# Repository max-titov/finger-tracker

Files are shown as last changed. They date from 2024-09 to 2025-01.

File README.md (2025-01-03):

# Finger Tracker Glove

Hardware that attaches to the back of your hand and fingertips that tracks 16 degrees of freedom. 

<p float="left">
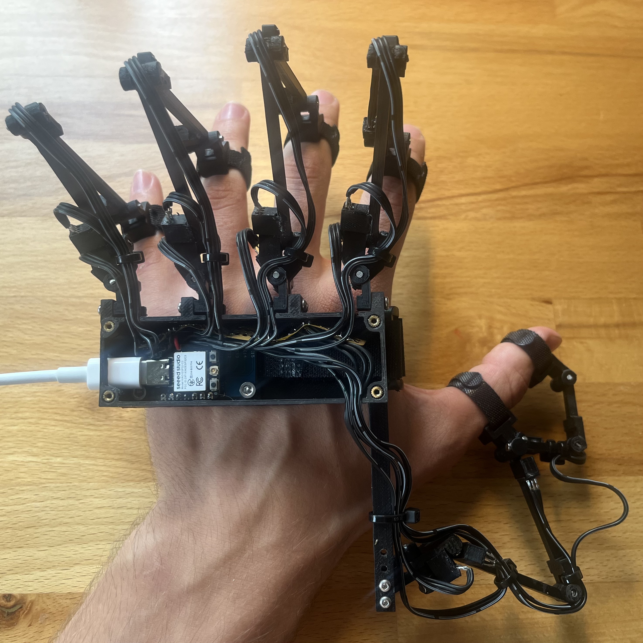
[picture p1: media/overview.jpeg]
  
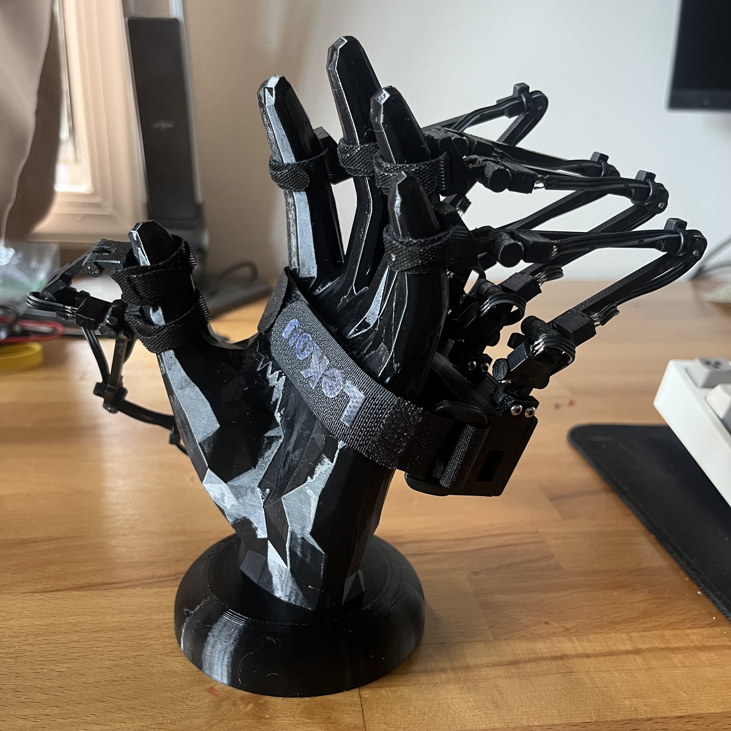
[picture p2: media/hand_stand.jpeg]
   
</p>

https://github.com/user-attachments/assets/3ccb0007-c99d-40c1-8628-71b2f0f8c4fa

## Description

The glove uses rotating neodymium magnets and hall effect sensors at each joint to measure rotation. The thumb has 4 sensors and the fingers have 3 each. Each sensor is wired up to a multiplexer and powered with a common GND/VCC strip. I used a XIAO ESP32C3 as the microcontroller for its small form factor. This project builds upon Nepyope's glove shown here: [Youtube](https://www.youtube.com/watch?v=iPtgvh6fNdQ).

## Getting Started

### 3D Printing

All the files are in the CAD folder. For Nepyope's parts I have just the STL with all of the pieces (and I dont use all of them). For my parts I have all of them as STLs and most of them have SLDPT and STEP versions.

Nepyope's Parts:
* 16x sensor boxes and lids
* Connecting rods (12 total, I used 11 of them as I changed one)
* 4x Finger second piece
* Thumb second piece

You can print the STL with all the parts and just use the ones listed above

My Parts:
* Enclosure
* Enclosure top
* Thumb bracket
* 4x finger endpiece
* Thumb endpiece
* Thumb middle piece
* Thumb first piece
* Thumb short rod (flipped from nepyope’s design)
* 4x Finger first joint

### Mechanical Hardware

* Finger straps [Amazon](https://www.amazon.com/dp/B0CJ52WJZY?ref=ppx_yo2ov_dt_b_fed_asin_title&th=1)
* Hand strap [Amazon](https://www.amazon.com/dp/B07CWV5JCT?ref=ppx_yo2ov_dt_b_fed_asin_title)
* 2mm steel pins
* M2 bolts and inserts
* M3 bolts and inserts
* 3mm by 3mm circular neodymium magnets [Amazon](https://www.amazon.com/dp/B0CCXYF5TR?ref=ppx_yo2ov_dt_b_fed_asin_title)

### Electrical Hardware

* Xiao ESP32C3
* 16 channel multiplexer [Amazon](https://www.amazon.com/dp/B01DLHKLNE?psc=1&ref=ppx_yo2ov_dt_b_product_details)
* 2.54mm pins
* 28 gauge 3 wire
* 28 gauge 1 wire
* 16x hall effect sensor [Amazon](https://www.amazon.com/dp/B09XQPCYNX?ref=ppx_yo2ov_dt_b_fed_asin_title)
* Flexible pcb [Adafruit](https://www.adafruit.com/product/1518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)

### Tools

* Soldering tools (iron, solder, flux, etc)
* Cutters, wire stripers, etc
* Superglue
* 1.5mm and 2.5mm allen keys

### Firmware

The firmware was made using PlatformIO in the Arduino framework. You can comment and uncomment the print functions to print raw values, adjusted angle values, or all the values in a single string. The raw value and adjusted angle values print in a way where Teleplot (serial plotter VSCode extension) can read and plot them. A teleplot layout is in the teleplot folder.

## License

This project is licensed under the MIT License - see the LICENSE file for details

## Acknowledgments

* [Nepyope Youtube](https://www.youtube.com/watch?v=iPtgvh6fNdQ)
* [Nepyope Github](https://github.com/nepyope/Project-Homunculus/tree/main)

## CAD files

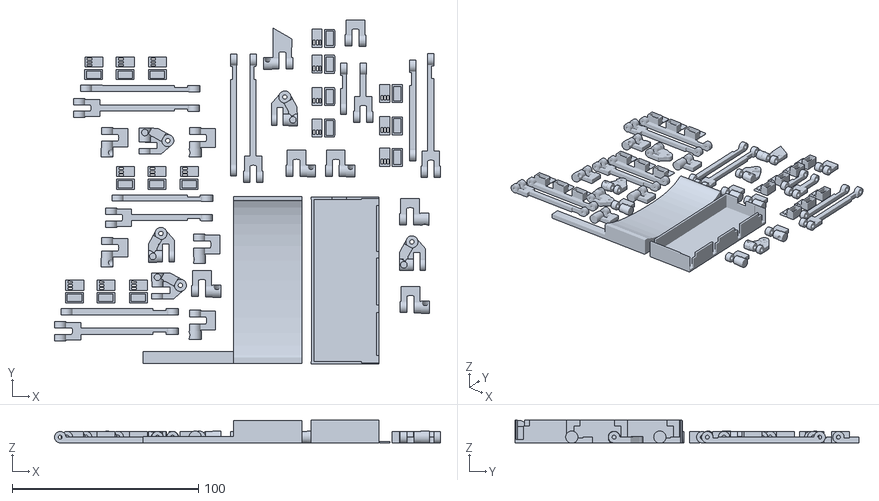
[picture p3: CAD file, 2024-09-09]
cad/homunculus_glove_nepyope.stl
207.2 x 184.7 x 12.3

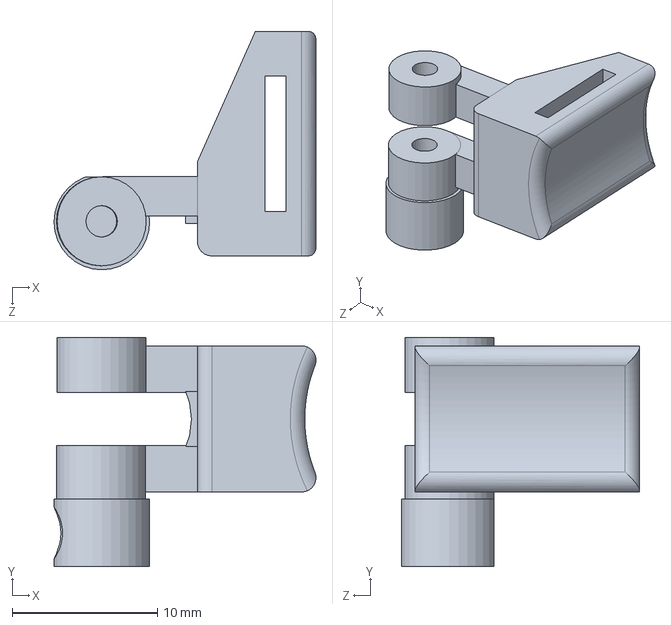
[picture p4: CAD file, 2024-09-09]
cad/SLDPRT/finger endpiece.SLDPRT
18.1 x 15.8 x 16.4 mm

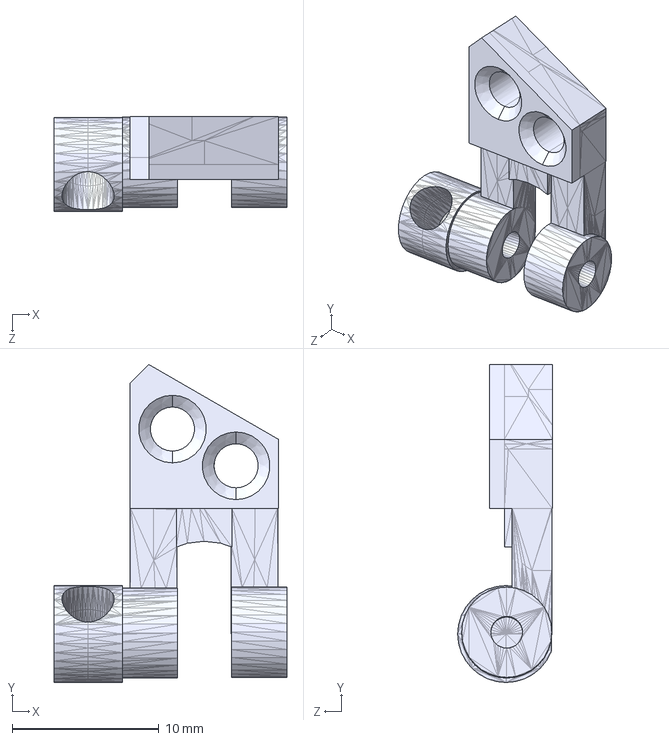
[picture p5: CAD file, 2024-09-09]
cad/STEP/thumb first piece v2.STEP
15.8 x 21.6 x 6.45 mm

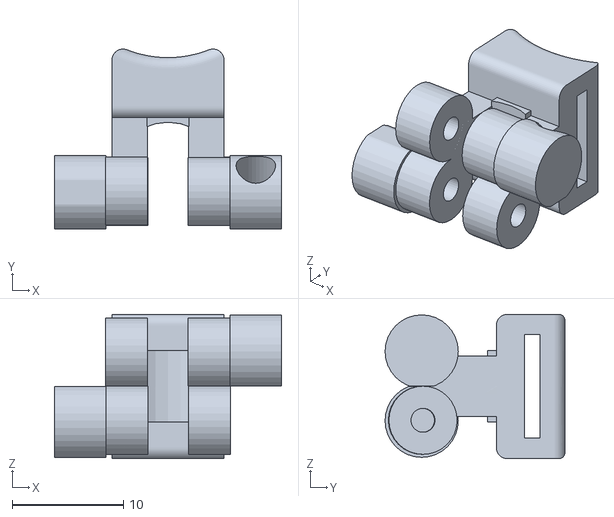
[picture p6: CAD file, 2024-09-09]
cad/STL/thumb middle v4.STL
20.4 x 16.2 x 13.0

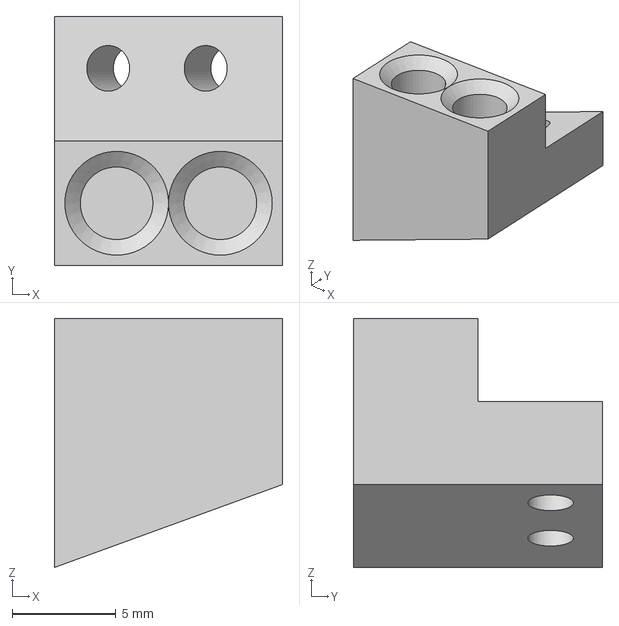
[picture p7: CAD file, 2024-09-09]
cad/STEP/thumb bracket v1.step
11.0 x 12.0 x 12.0 mm

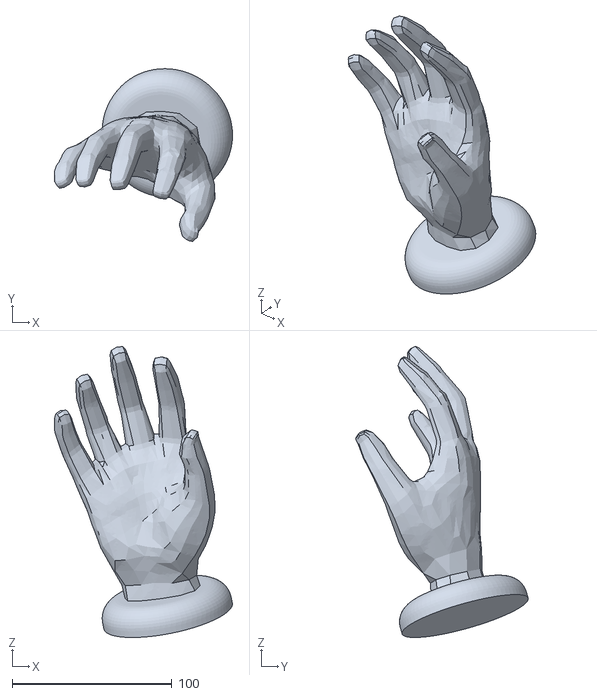
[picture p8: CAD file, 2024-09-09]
cad/STL/hand stand v1.stl
111.3 x 107.9 x 181.9

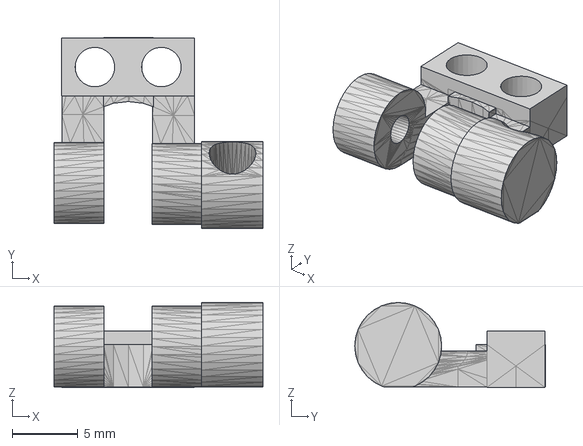
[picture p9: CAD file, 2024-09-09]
cad/STEP/first joint v2.step
15.8 x 14.5 x 6.45 mm

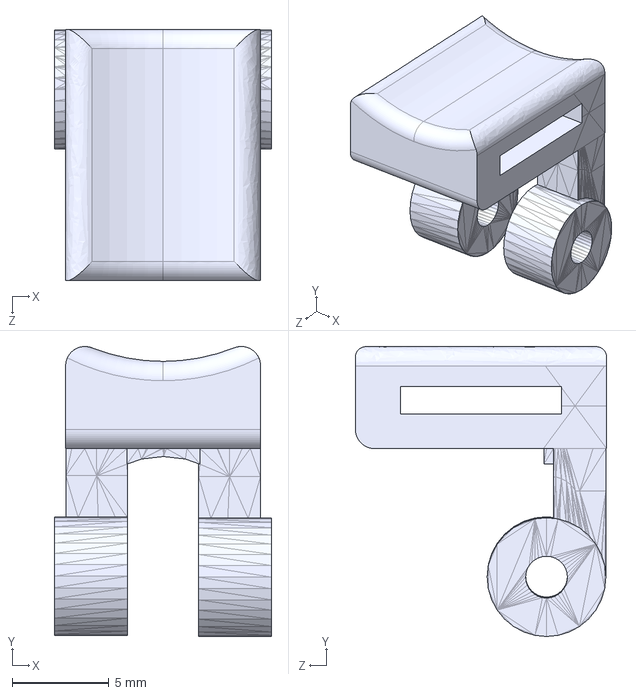
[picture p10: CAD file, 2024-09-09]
cad/STEP/thumb end v2.STEP
11.2 x 15.0 x 13.0 mm

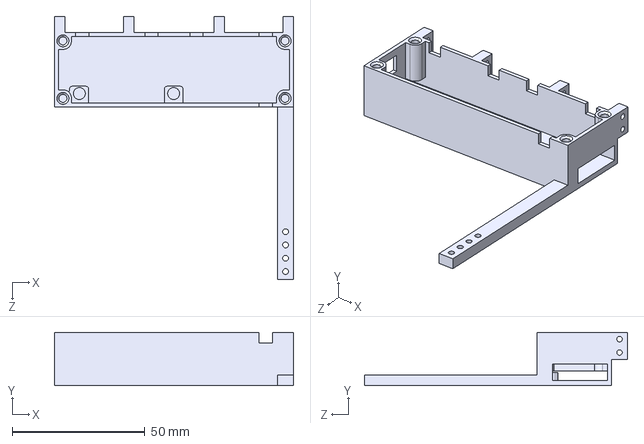
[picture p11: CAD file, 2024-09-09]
cad/STEP/enclosure v4.STEP
90.0 x 20.0 x 99.0 mm

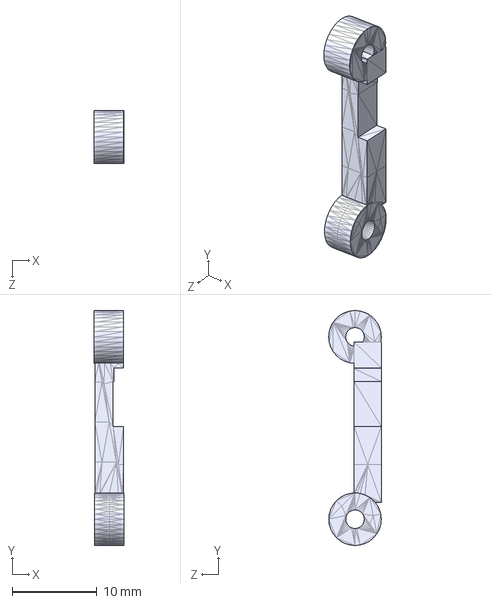
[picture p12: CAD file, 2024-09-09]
cad/STEP/thumb short rod v3.STEP
3.55 x 27.8 x 6.24 mm

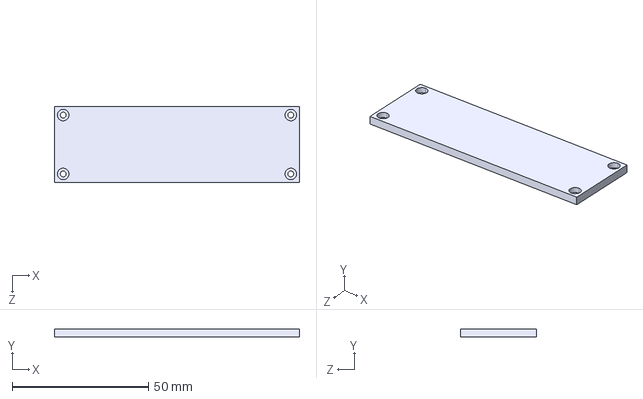
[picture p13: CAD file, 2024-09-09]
cad/STEP/enclosure top v2.STEP
90.0 x 3.00 x 28.0 mm

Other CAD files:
cad/SLDPRT/enclosure top v2.SLDPRT
cad/SLDPRT/enclosure v4.SLDPRT
cad/SLDPRT/thumb end v2.SLDPRT
cad/SLDPRT/thumb first piece v2.SLDPRT
cad/SLDPRT/thumb short rod v3.SLDPRT
cad/STL/enclosure top v2.STL
cad/STL/enclosure v4.STL
cad/STL/finger endpiece.STL
cad/STL/first joint v2.stl
cad/STL/thumb bracket v1.stl
cad/STL/thumb end v2.STL
cad/STL/thumb first piece v2.STL
cad/STL/thumb short rod v3.STL

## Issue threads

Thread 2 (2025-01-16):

Hall Effect sensors

sisyphean-task, 2025-01-16:
Hi,

I've been trying to build this project for use with the Dexhand as well, but I'm a bit confused in a few areas, particularly surrounding the hall effect sensors.
First, how are they oriented in the boxes? I have a rough sketch below with my potential assumptions from your and nepyope's implementations, but it is hard to tell where they are when obfuscated.
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

Also, when turning the output from the sensors into an angle, I noticed a polynomial approximation was used to map the presumably nonlinear data into the linear angle. Did you create the method behind this calibration, or was this shared by nepyope? I could not find anything from nepyope's repo about it. I would assume multiple known angles were tested and then the output at each was mapped to create a scatter, and the points were fit with a polynomial curve with the approximate constants in the code.

It would be greatly appreciated if you shared what you know about these! :)

abrar360, 2025-05-09:
I'm wondering the same thing and stumbled upon your issue. Were you able to figure it out?

I'm planning to just test which side of the sensor seems the most sensitive and orient that side downward w.r.t your drawings. I'm guessing it will likely end up like the leftmost diagram in your drawings above.

sisyphean-task, 2025-05-09:
Yep, use the leftmost drawing. Magnetic flux plate of the sensor is parallel to the larger flat faces.

abrar360, 2025-05-09:
Thanks! I just tested with a magnet and it seems like the narrower side of the sensor (with the writing on it) is slightly more sensitive than the larger side, so I'm glueing it upside down to the way it's drawn on the left most one but I don't think it makes a big difference. It makes it more annoying though since you have to bend the pins to the other side.

abrar360, 2025-05-11:
@sisyphean-task Do you happen to know where the thumb bracket piece goes? That's the only piece I can't seem to figure out.

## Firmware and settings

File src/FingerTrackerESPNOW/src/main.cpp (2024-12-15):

#include <Arduino.h>

#include <HapticGlove_ESPNOW.h>
#include <FingerTracking.h>
#include <HallEffectSensors.h>

#define PEER_MAC {0x24, 0xEC, 0x4A, 0x45, 0x23, 0x80}
//{0x3C, 0x84, 0x27, 0x14, 0x7B, 0xB0}

void sendData() {
    uint8_t fpos[SENSOR_COUNT];
    float wpos[3];
    uint8_t apos[3];
    for(int i = 0; i < SENSOR_COUNT; i++){
        fpos[i] = (uint8_t)angles[i];
    }
    //send random data for wrist position and arm position
    for(int i = 0; i < 3; i ++){
        wpos[i] = 0;
        apos[i] = random(1, 255);
    }
    //set wrist pitch position to be slightly backwards to stabilize it
    wpos[1] = -20;

    //position_packet.messages_rec = glove_messages_rcv;

    glove_sendData(fpos, wpos, apos);

    //glove_messages_send_attempt += 1;
}

void setup() {
	uint8_t mac[] = PEER_MAC;
	glove_ESPNOWsetup(mac, 115200);
	fingerTrackingSetup();
}

void loop() {
	calcFingerAngles();
	printFingerAngles();

	sendData();

}

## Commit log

2024-09-09 changed file structure and cloned FingerTracker16DOF from previous file system
2024-09-09 added cad files
    [enclosure top v2.SLDPRT, enclosure top v2.STEP, enclosure top v2.STL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]
2024-09-09 added nepyope stl
    [homunculus_glove_nepyope.stl]
2024-12-15 actually new project called FingerTrackerESPNOW to demonstrate library usage and ESPNOW functionality
